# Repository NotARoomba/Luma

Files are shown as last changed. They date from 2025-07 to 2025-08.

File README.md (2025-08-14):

<h1 align="center">
  <br>
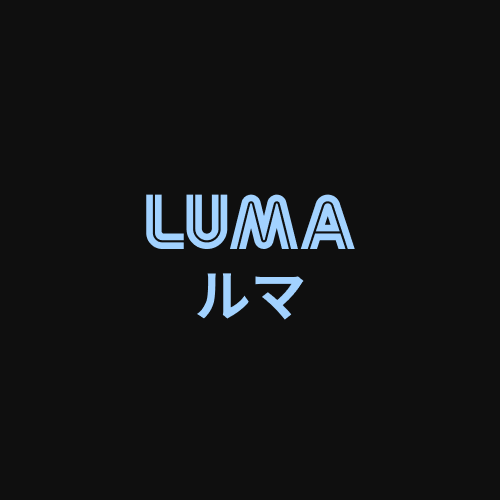
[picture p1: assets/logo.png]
Luma
  
  <br>
  Luma
  <br>
</h1>

<h4 align="center">
A Minecraft inspired lantern with bluetooth!

</h4>

<div align="center">





</div>

<p align="center">
  <a href="#key-features">Key Features</a> •
  <a href="#case-and-cad">Case & CAD</a> •
  <a href="#pcb">PCB</a> •
  <a href="#bom">BOM</a> •
  <a href="#credits">Credits</a> •
  <a href="#license">License</a>
</p>

## Key Features

- Bluetooth/Wifi capabilitis
- Bright configurable LED's
- Easy to assemble case
- App to control/change colors

## Case and CAD

The case includes:

- 3D printed parts: The base, walls, top, and chain
- Glueable inserts and acrylic panes

Designed in Fusion 360.

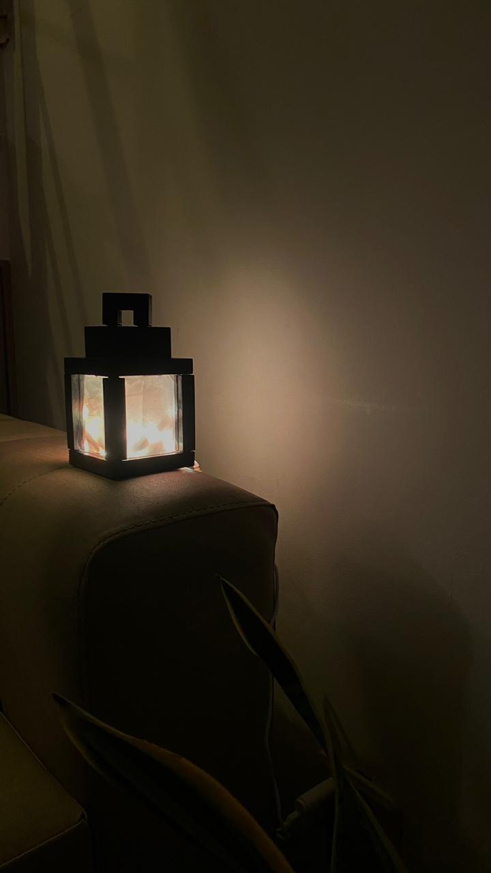
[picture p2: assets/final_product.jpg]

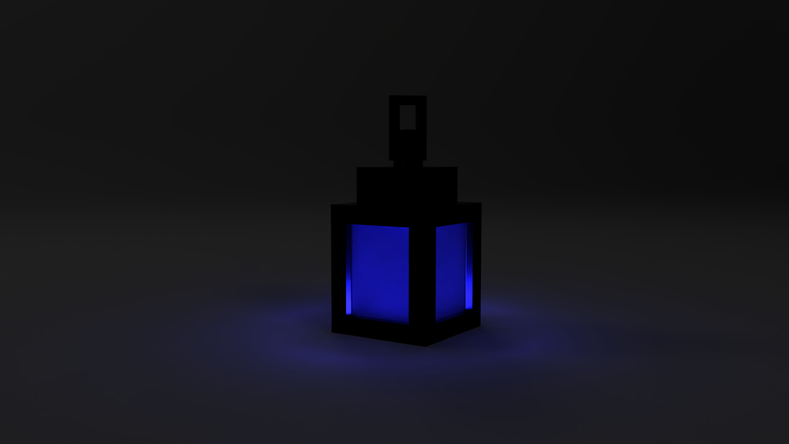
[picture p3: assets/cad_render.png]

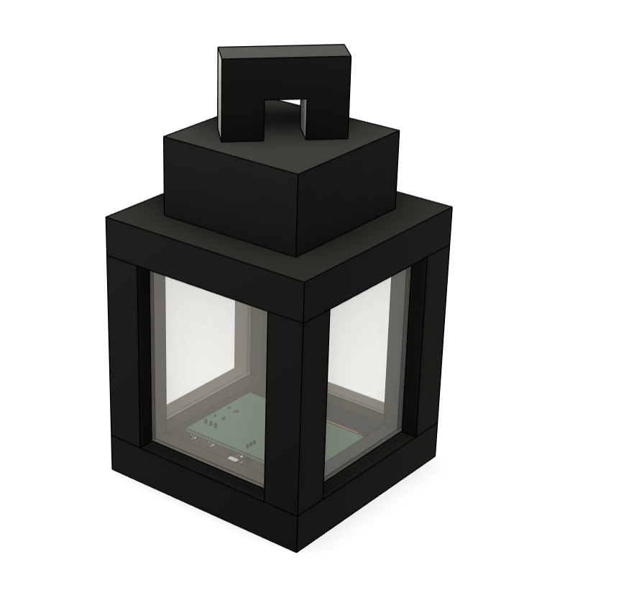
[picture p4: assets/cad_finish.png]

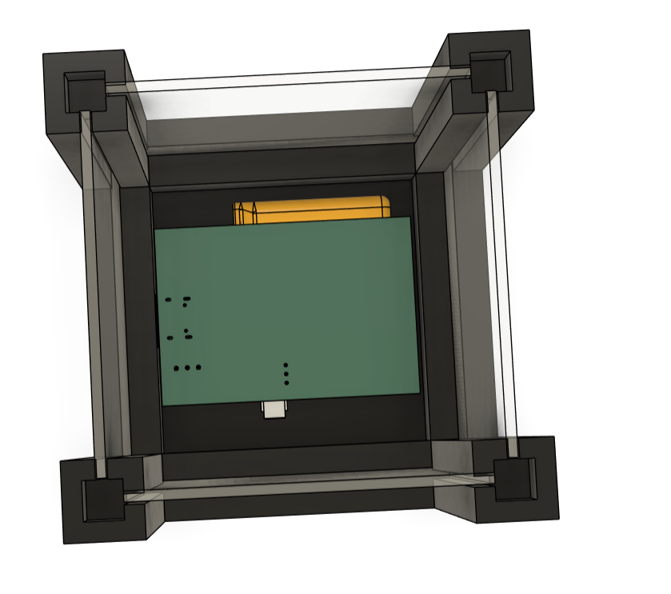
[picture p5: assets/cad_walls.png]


## PCB

Designed in KiCad. Notable points:

- ESP32-WROOM-32E for bluetooth support
- LiPo battery charging circuit
- USB-C
- LED Header to add custom LED's

### Main Board

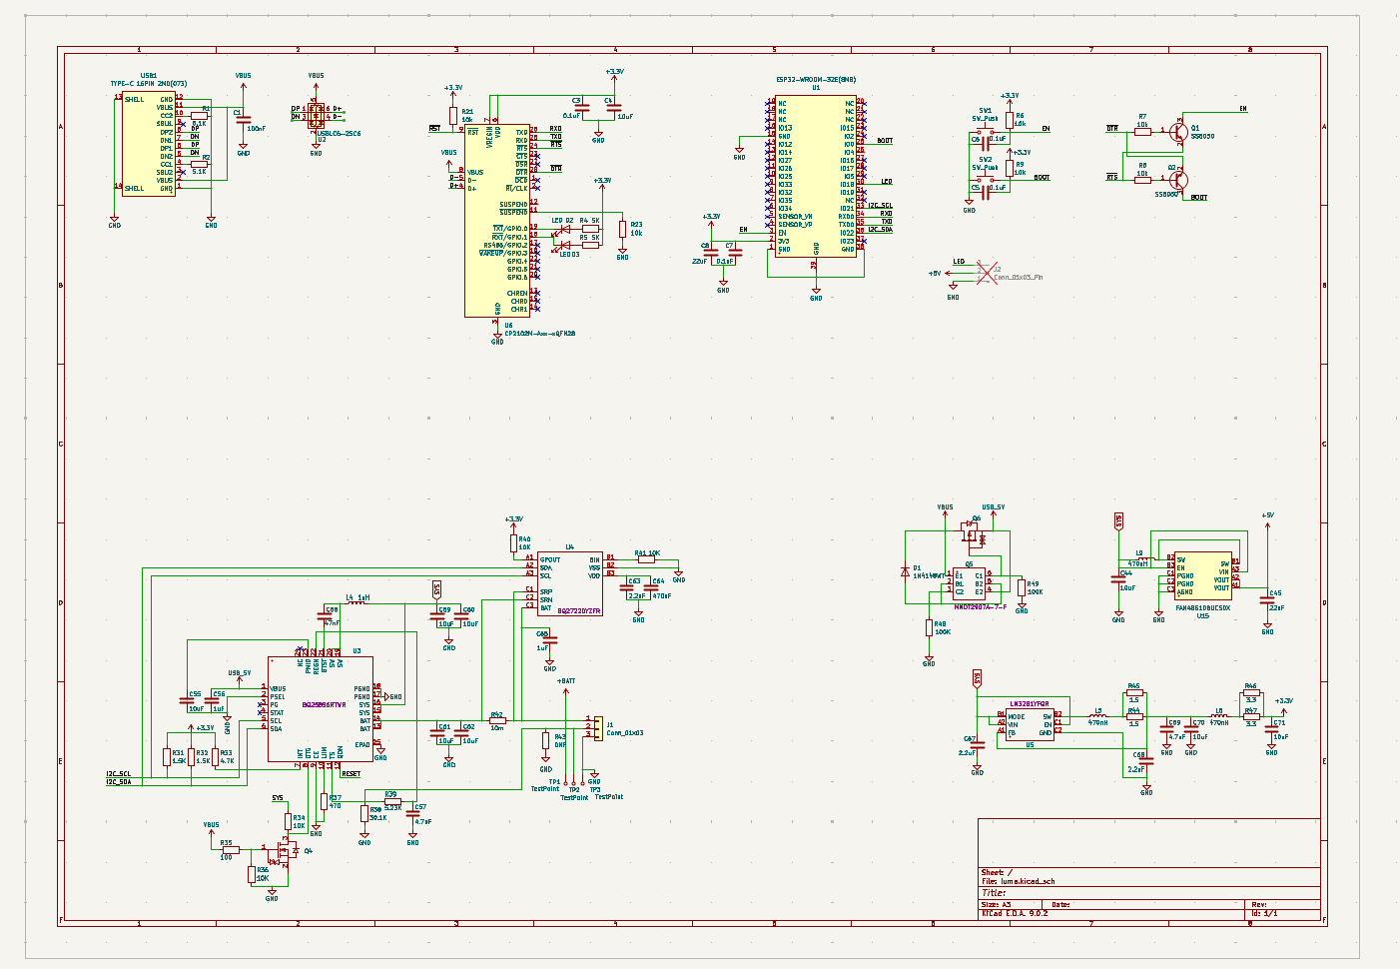
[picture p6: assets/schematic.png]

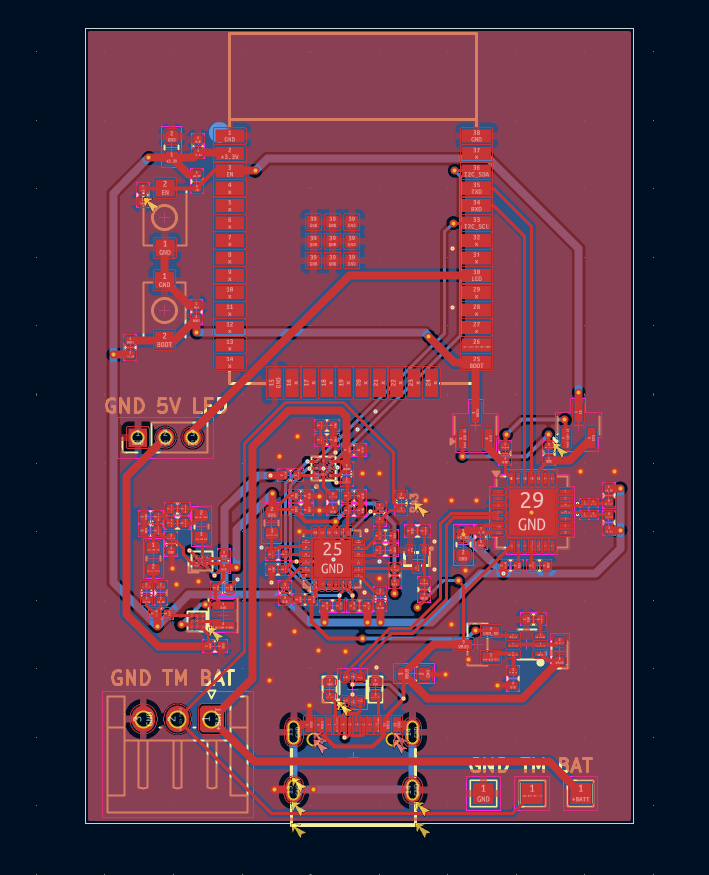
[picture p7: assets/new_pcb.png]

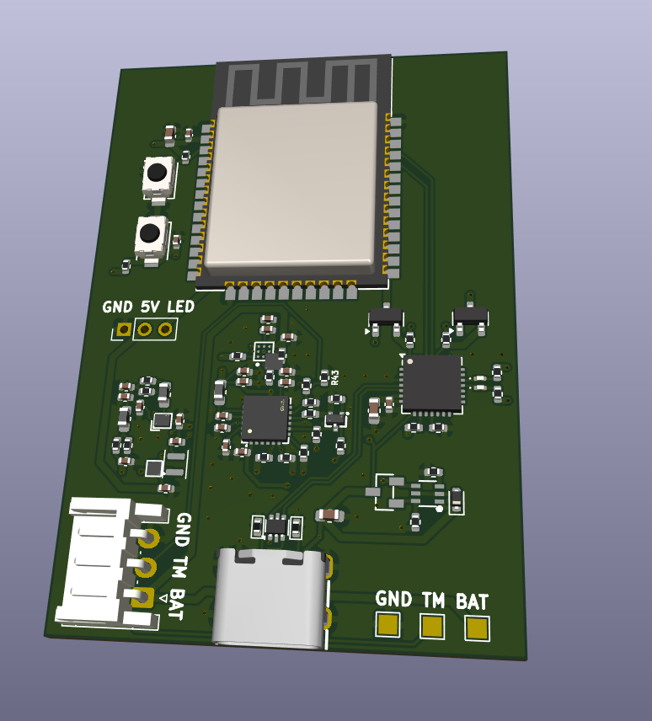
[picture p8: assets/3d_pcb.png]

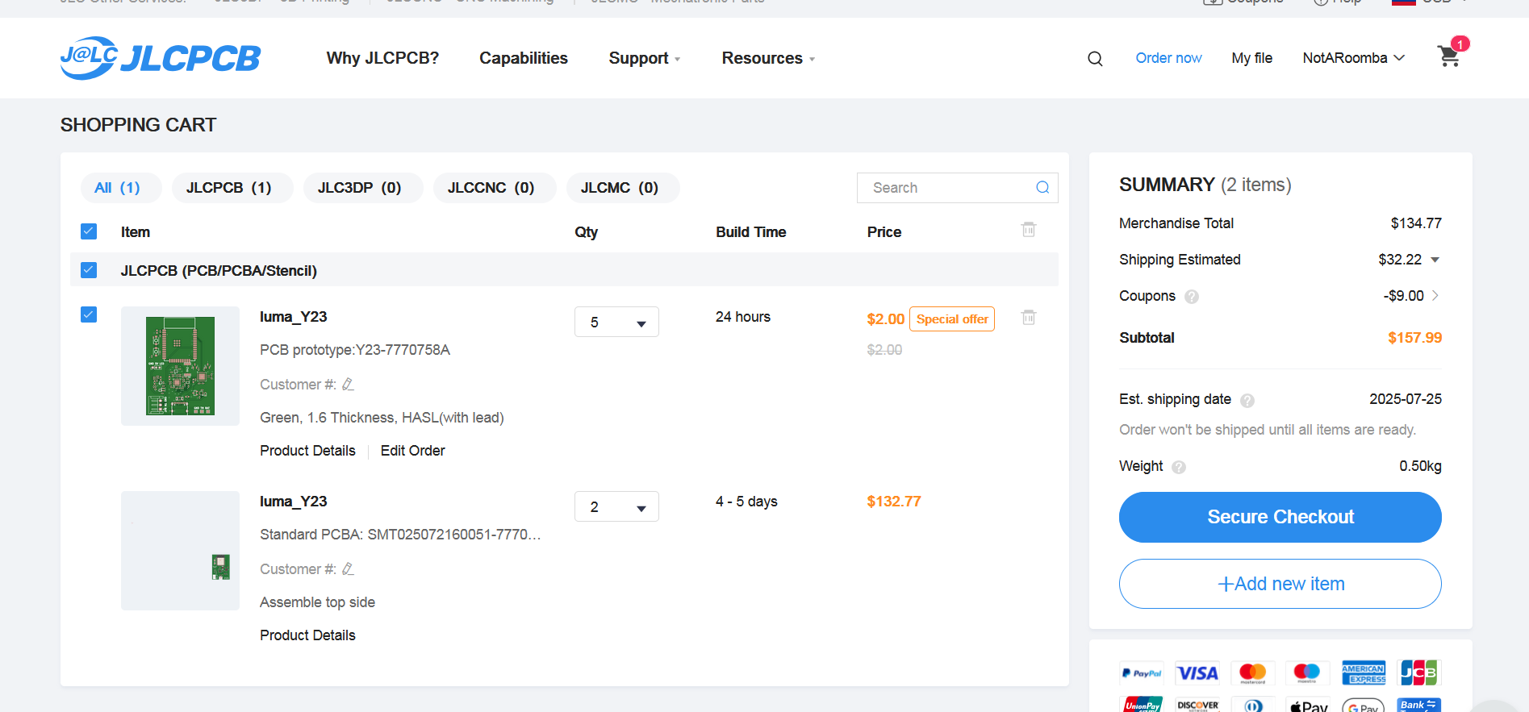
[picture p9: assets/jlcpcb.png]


## BOM

| Item | Price (USD) | Source |
| --- | --- | --- |
| PCB | 134.77 | JLCPCB |
| 3D Printed Parts | 0.00 | (already have a 3D printer) |
| Acrylic Panes | 0.00 | (already have) |
| LED Strip | 0.00 | (already have) |
| LiPo 1200mAh | 12.00 | [Online Marketplace (Aliexpress takes 1 month)](https://articulo.mercadolibre.com.co/MCO-897219547-bateria-37v-1200mah-litio-lipo-35-x-6cm-ancho-05cm-_JM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) |
| **Total** | 146.77 | |

## Credits

This project uses:

- [KiCad](https://www.kicad.org/)
- [VSCode](https://code.visualstudio.com/)
- [Fusion 360](https://www.autodesk.com/products/fusion-360/overview)

## You may also like...

- [Niveles De Niveles](https://github.com/NotARoomba/NivelesDeNiveles) – Real-time flood alert app
- [Linea](https://github.com/NotARoomba/Linea) – An EMR tablet
- [Tamaki](https://github.com/NotARoomba/Tamaki) – A cute HackPad

## License

MIT

---

> [notaroomba.dev](https://notaroomba.dev) &nbsp;&middot;&nbsp;
> GitHub [@NotARoomba](https://github.com/NotARoomba)

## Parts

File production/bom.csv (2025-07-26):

Designator | Footprint | Quantity | Value | LCSC Part #
C1 | 0603 | 1 | 100nF
C3, C5, C6, C7 | 0402 | 4 | 0.1uF
C4 | 0603 | 1 | 10uF
C44, C55, C59, C60, C61, C62, C70, C71 | 0402 | 8 | 10uF
C45 | 0402 | 1 | 22uF
C56, C65 | 0402 | 2 | 1uF
C57, C69 | 0402 | 2 | 4.7uF
C58 | 0402 | 1 | 47nF
C63, C67, C68 | 0402 | 3 | 2.2uF
C64 | 0402 | 1 | 470nF
C8 | 0603 | 1 | 22uF
D1 | D_SOD-523 | 1 | 1N4148WT
D2, D3 | 0201 | 2 | LED
J1 | JST_EH_S3B-EH_1x03_P2.50mm_Horizontal | 1 | Conn_01x03 | C263754
J2 | PinHeader_1x03_P2.00mm_Vertical | 1 | Conn_01x03_Pin
L4 | 0603 | 1 | 1uH
L5, L6 | 0603 | 2 | 470nH
L9 | L_Murata_DFE201610P | 1 | 470nH | C882980
Q1, Q2 | SOT-23 | 2 | SS8050 | SS8050-HF
Q4 | SOT-523-3_L1.6-W0.8-P1.00-LS1.6-BR | 1 | ~ | C155524
Q5 | SOT-363_L2.0-W1.3-P0.65-LS2.1-BL | 1 | ~ | C460232
Q6 | SOT-23-3_L2.9-W1.3-P1.90-LS2.4-BR | 1 | ~ | C177033
R1, R2 | 0402 | 2 | 5.1K
R21, R23, R6, R7, R8, R9 | 0402 | 6 | 10k | CRCW040210K0FKED
R31, R32 | 0402 | 2 | 1.5K
R33 | 0402 | 1 | 4.7K
R34, R36, R40, R41 | 0402 | 4 | 10K
R35 | 0402 | 1 | 100
R37 | 0402 | 1 | 470
R38 | 0402 | 1 | 30.1K
R39 | 0402 | 1 | 5.23K
R4, R5 | 0402 | 2 | 5K | CRCW040210K0FKED
R42 | R2512 | 1 | WW25WR010FTL | C171418
R43 | 0402 | 1 | DNP
R44, R45 | 0402 | 2 | 1.5
R46, R47 | 0402 | 2 | 3.3
R48, R49 | 0402 | 2 | 100K
SW1, SW2 | SW-SMD_L3.9-W3.0-P4.45 | 2 | SW_Push | C720477
TP1, TP2, TP3 | TestPoint_Pad_1.5x1.5mm | 3 | TestPoint
U1 | WIFI-SMD_ESP32-WROOM-32E | 1 | ESP32-WROOM-32E(8MB) | C701342
U15 | WLCSP-9_L1.2-W1.2-R3-C3-P0.40-BL | 1 | FAN48610BUC50X | C890711
U2 | SOT-666 | 1 | USBLC6-2SC6 | USBLC6-2SC6
U3 | QFN-24_L4.0-W4.0-P0.50-TL-EP2.7 | 1 | ~ | C181475
U4 | DSBGA-9_L1.7-W1.6-R3-C3-P0.50-BL | 1 | ~ | C528617
U5 | DSBGA-6_L1.4-W1.1-R3-C2-P0.40-BL | 1 | ~ | C2070970
U6 | QFN-28-1EP_5x5mm_P0.5mm_EP3.35x3.35mm | 1 | CP2102N-Axx-xQFN28 | C964632
USB1 | USB-C-SMD_TYPE-C-6PIN-2MD-073 | 1 | TYPE-C 16PIN 2MD(073) | C2765186

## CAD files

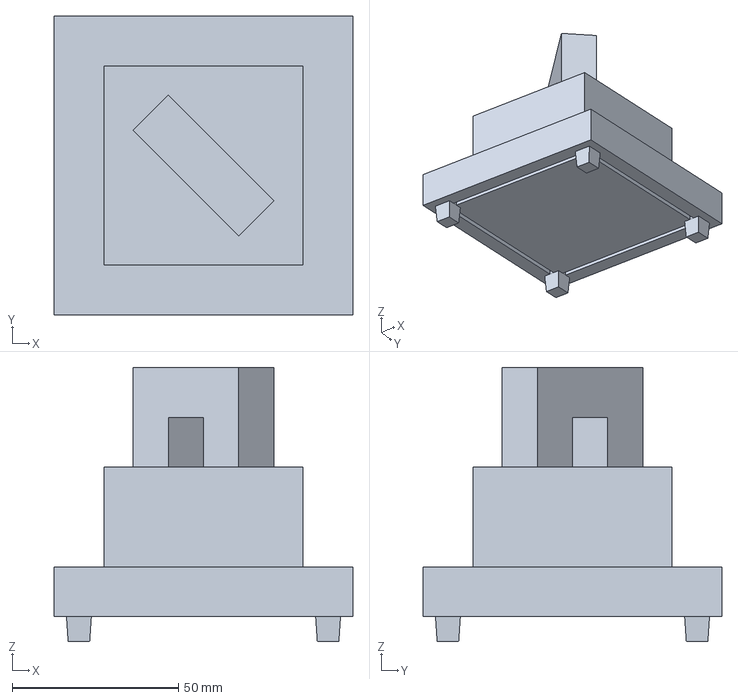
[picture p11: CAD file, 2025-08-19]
production/Top_Complete.step
90.0 x 90.0 x 82.5 mm

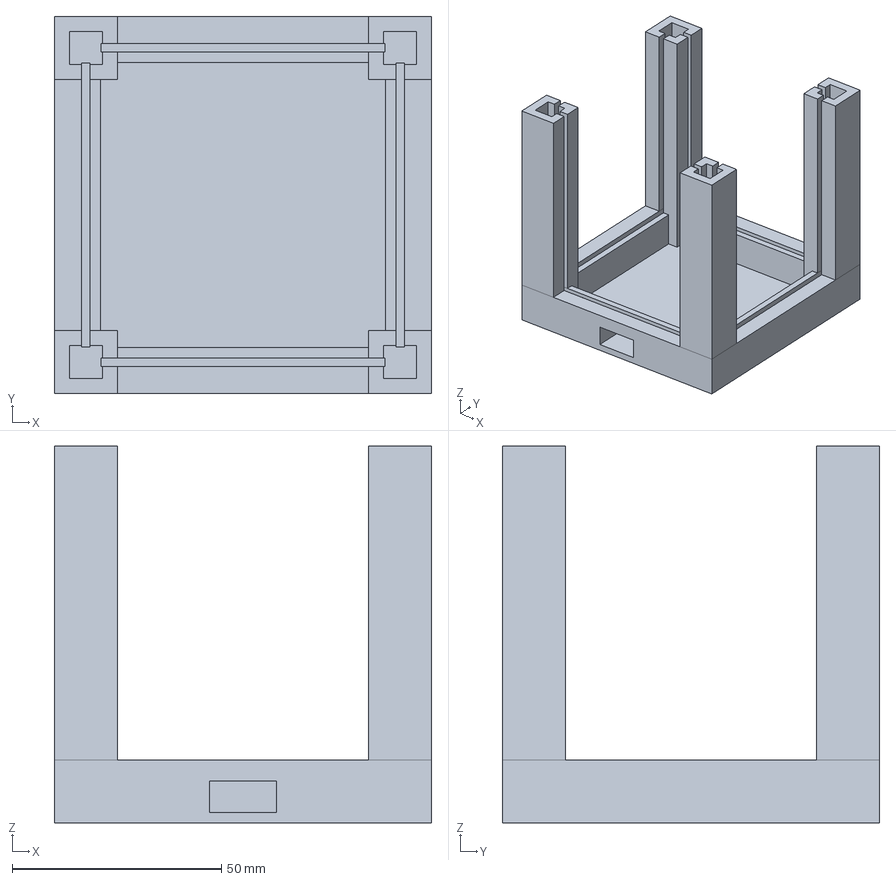
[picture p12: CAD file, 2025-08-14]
production/Base_Complete.step
90.0 x 90.0 x 90.0 mm

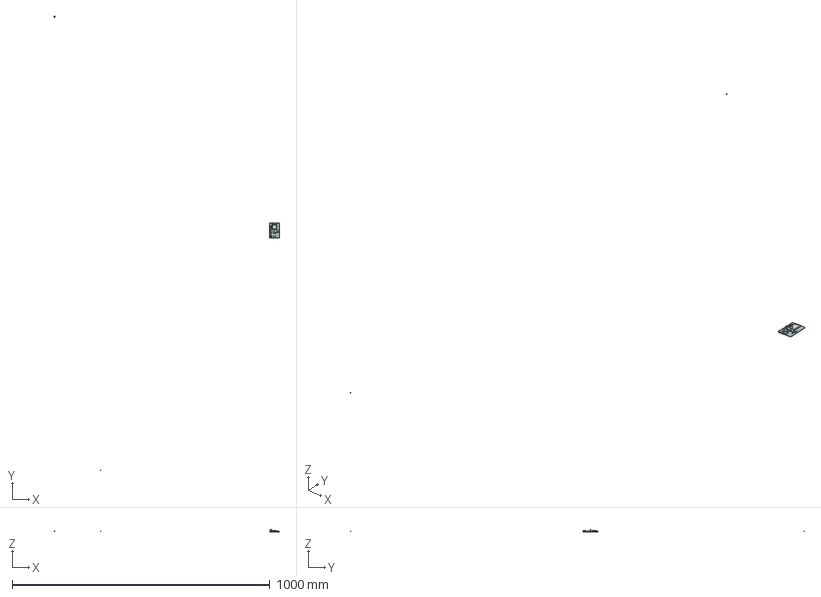
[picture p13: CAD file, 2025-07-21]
hardware/pcb/luma.step
874.2 x 1760.2 x 9.20 mm
QFN-28-1EP_5x5mm_P0.5mm_EP3.35x3.35mm
C_0603_1608Metric x 3
R_0402_1005Metric x 29
JST_EH_S3B-EH_1x03_P2.50mm_Horizontal
C_0402_1005Metric x 22
SW-SMD_L3.9-W2.9-H2.0-LS4.8 x 2
L_0603_1608Metric x 3
SOT-363-6P_L2.0-W1.3-H1.1-LS2.0-P0.65
SOT-23 x 2
SOT-23-3P_L2.9-W1.3-H1.0-LS2.4-P0.95
WIFI-SMD_L25.5-W18.0-H3.1-ESP32-WROOM-32E
SOT-523-3P_L1.6-W0.8-H0.9-LS1.6-P0.50
DSBGA-6_L1.4-W1.1-R3-C2-P0.40-BL
LED_0201_0603Metric x 2
QFN-24_L4.0-W4.0-P0.50-TL-EP2.7
DSBGA-9_L1.7-W1.6-H0.6-R3-C3-P0.50-BL
SOT-666
USB-C-SMD_TYPE-C-6PIN-2MD-073
PinHeader_1x03_P2.00mm_Vertical
D_SOD-523
WLCSP-9_L1.2-W1.2-H0.6-R3-C3-P0.40-BL
luma_PCB

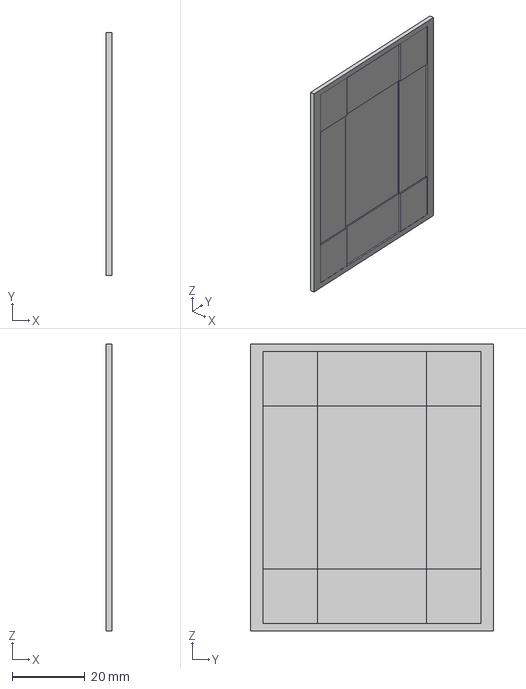
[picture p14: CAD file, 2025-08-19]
production/Window.step
1.60 x 67.0 x 79.0 mm

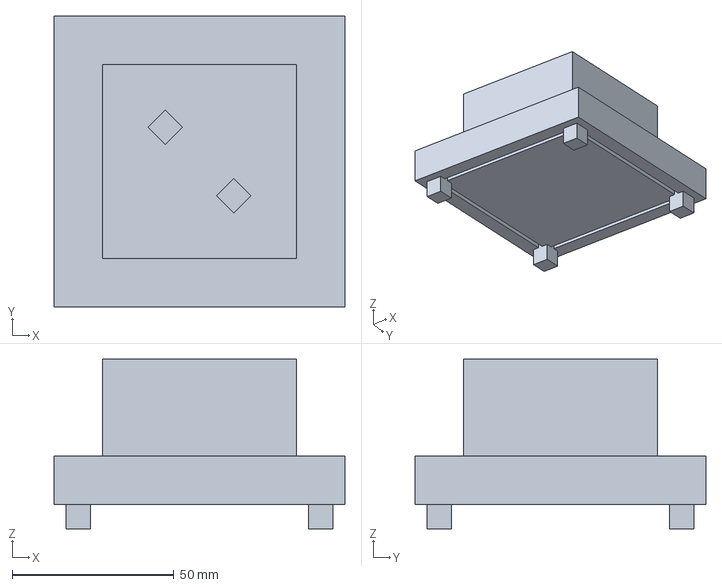
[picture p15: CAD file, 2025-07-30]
production/Top.step
90.0 x 90.0 x 52.5 mm

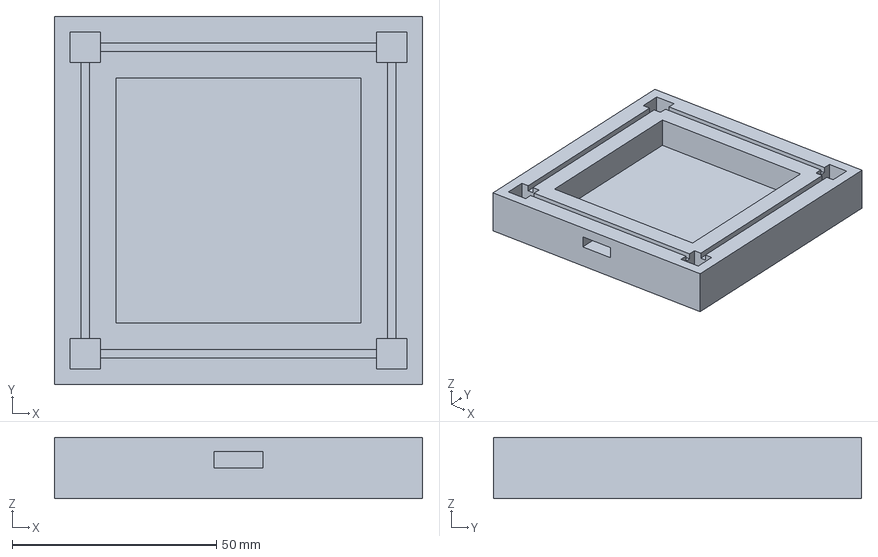
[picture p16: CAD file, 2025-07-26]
production/Bottom.step
90.0 x 90.0 x 15.0 mm

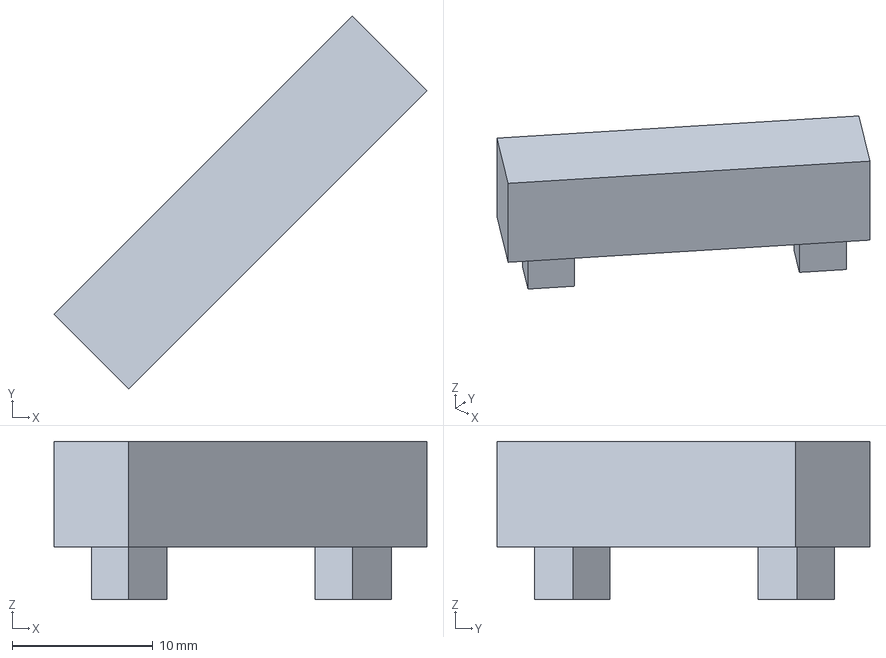
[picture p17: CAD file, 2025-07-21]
production/Chain_Top.step
26.5 x 26.5 x 11.2 mm

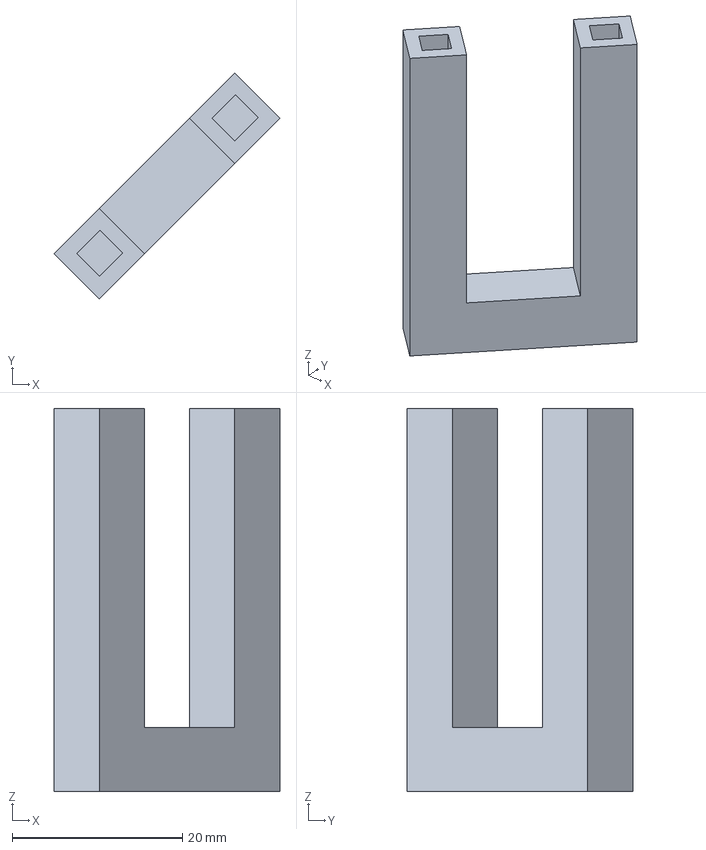
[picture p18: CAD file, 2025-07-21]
production/Chain_Bottom.step
26.5 x 26.5 x 45.0 mm

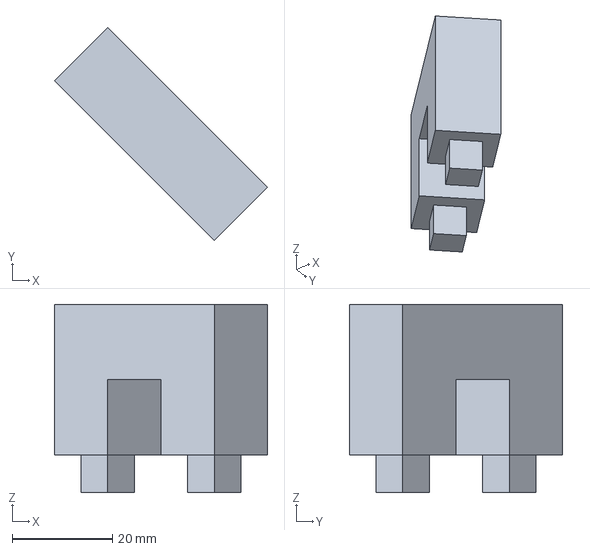
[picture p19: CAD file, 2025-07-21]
production/Handle.step
42.4 x 42.4 x 37.5 mm

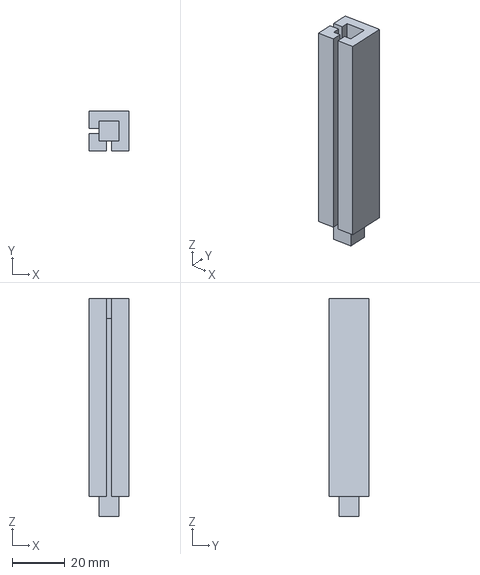
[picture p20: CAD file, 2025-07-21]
production/Leg.step
15.0 x 15.0 x 82.5 mm

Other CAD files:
hardware/cad/Luma v33.f3z
hardware/cad/Luma v40.f3z
production/Window.f3z

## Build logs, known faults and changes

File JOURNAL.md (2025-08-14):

---
title: "Luma"
author: "Nathan Alspaugh (NotARoomba)"
description: "A minecraft inspired lantern controllable by a custom app."
created_at: "2025-07-16"
time_spent: ~21 Hours
---

# July 16: Start and Schematic Design

I was scrolling TikTok out of boredom when I found a minecraft lantern that someone was selling and that could be controlled by an IR remote and in that moment I thought of a way to improve it so that's when Luma was started. I wanted to make a minecraft lantern that can be controlld by an app/bluetooth and that you can give to your friends to communicate through lights.

To do this I would need a chip that has bluetooth/wifi (I have designd my own before and would like to save myself the time lol) so I ended up using an ESP32-WROOM-32E(8MB) along with 9 LED's in a 3x3 matrix. I planned on having it be charged through USB-C and connect to a LiPo battery. I would make the case 3D-printeable and inclue acrylic panels with parchment paper to create a sort of "opacity". After having a clear idea of what I wanted to make, I started wiring up the components.

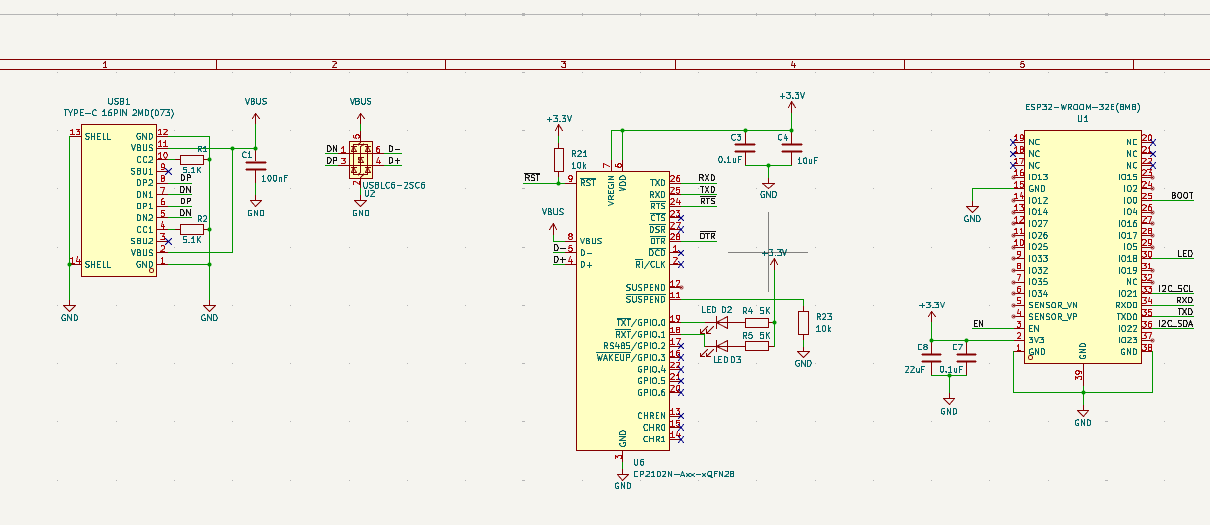
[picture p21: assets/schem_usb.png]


I started off with the ESP32 and the USB-C circuit bassed off of the application note before going to sleep.

**Time Spent:** 4 Hours

# July 17: Finish Schematic and PCB

After making part of the schematic I started work on the battery charging circuits, reusing a design that I implmented in my other project (Linea). Then I added the LED's and connected them to the ESP32.

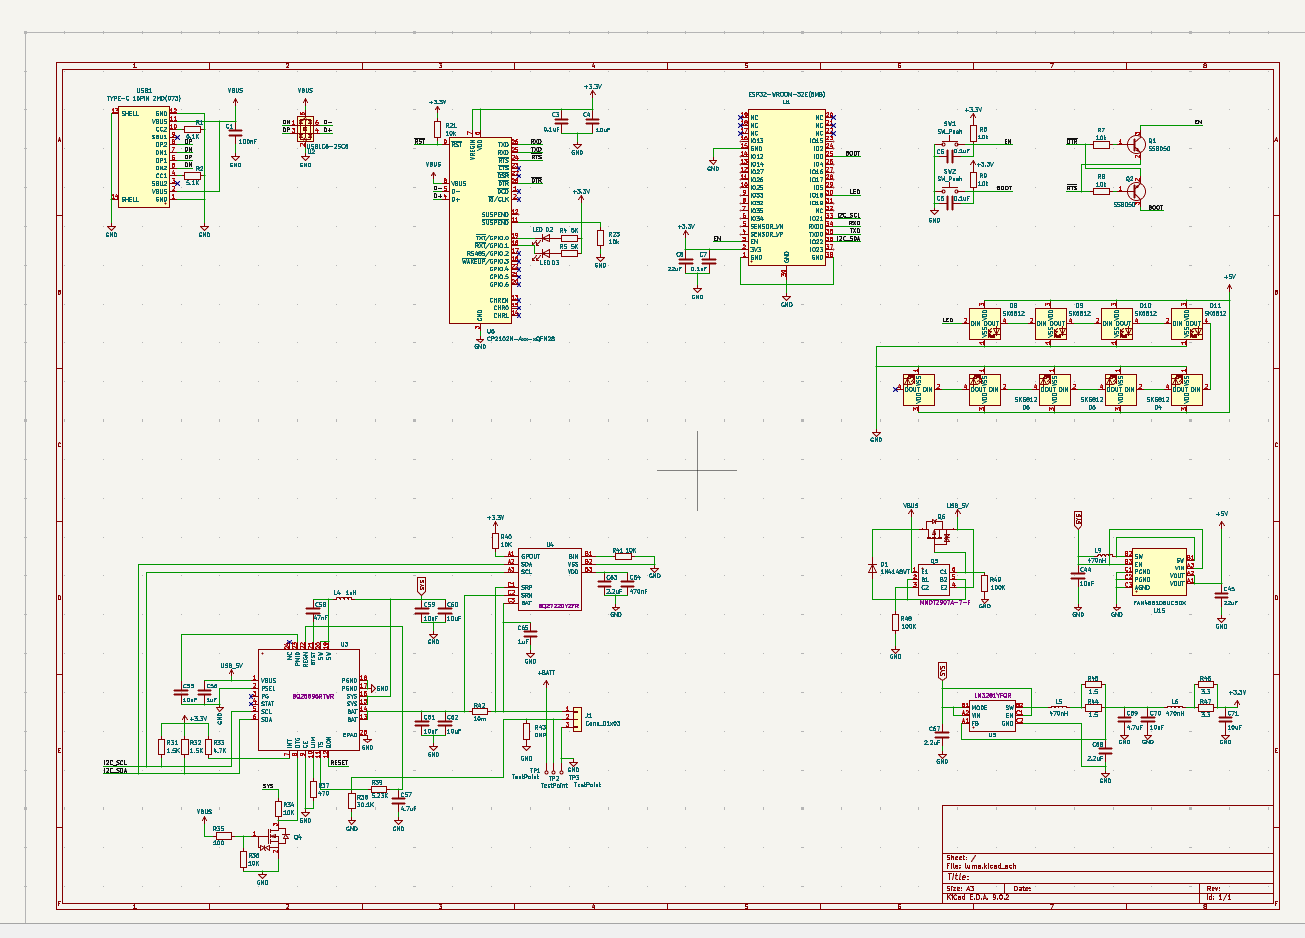
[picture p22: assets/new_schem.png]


After that I started wiring and grouping the components to organize the wiring and make it easier. I decided to make 2 ground planes for the fun of it and wire all the components on one side and then the LED's on the other. I planned on the board being on the bottom or top of the case so the LED's could illuminate the area well.

After a while I ended up with this, but then didn't like how the board was not modular or that I couldn't change the number of LED's (just in case) so I decided to remake the board out of concerns that the 9 LED's wouldn't be bright enough.

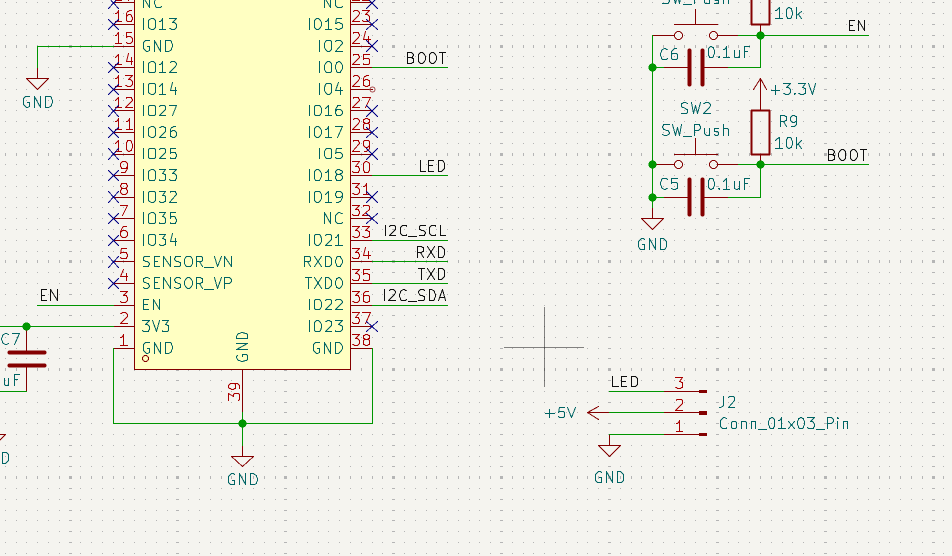
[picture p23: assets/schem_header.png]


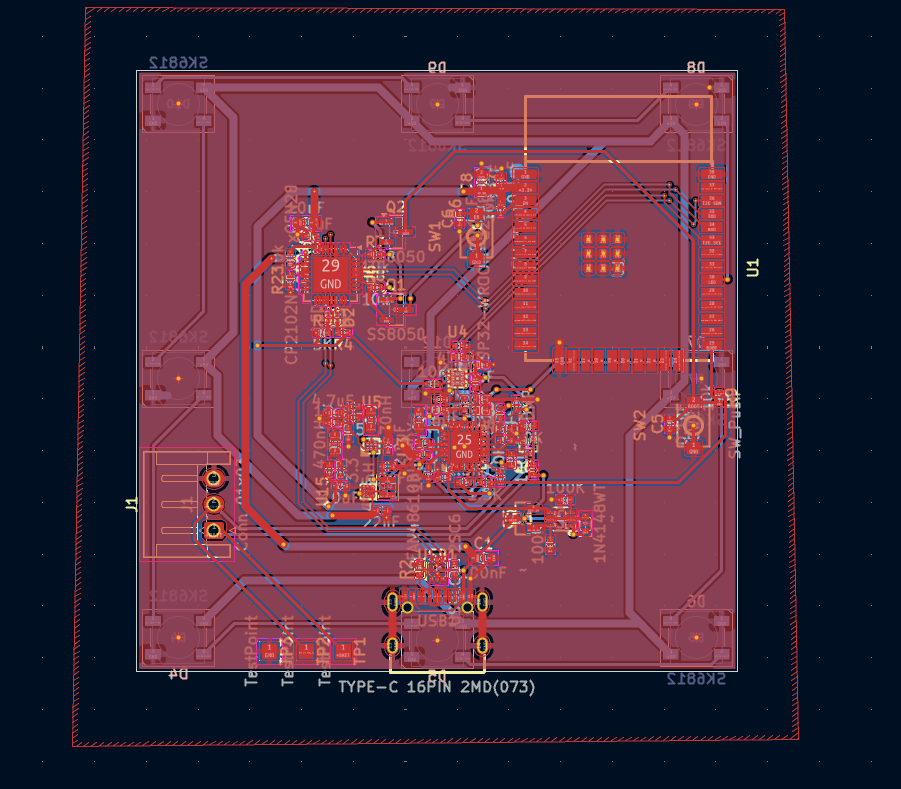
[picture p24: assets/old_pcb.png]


**Time Spent:** 7 Hours

# July 18: Start CAD

I took a break from the schematics and decided to work on the case.
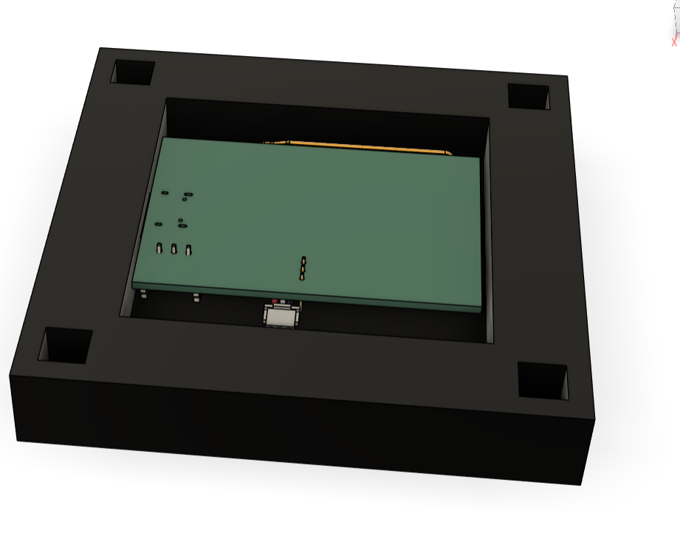
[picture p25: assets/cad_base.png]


I wanted the case to be modular so I created some insets in the base to add the walls.



I then created the walls of the lantern with more insets for the acrylic panels of the case. I decided to use acrylic panels of 2 mm so that the light from inside could get through.



After creating the walls, I added the top (with mroe insets) and then started working on the chains. I also wanted them to be modular and easy to asssemble so I added more inserts to be able to glue them later.

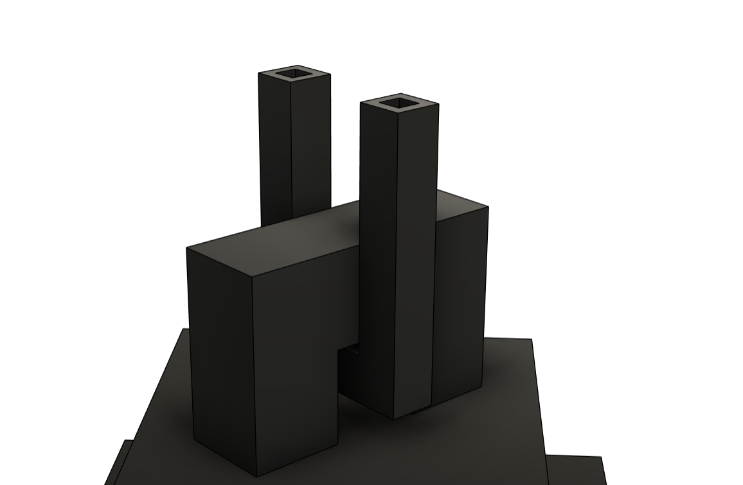
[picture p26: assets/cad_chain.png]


**Time Spent:** 5 Hours

# July 19-20: Finish New PCB and Code

After starting again, I removed all of the LED's and added a header to be able to solder a strip of LED's to allow for a more modular approach.



I also created the code using C++ (arduino). I added a test code to get the lights working as I plan to add the app functionality when I build the lamp.

**Time Spent:** 5 Hours

# August 6

The parts finally came in and I went to work on constructing the lamp before the deadline. Just a tiny problem: I forgot to add tolerances. So I had to hack away at the grooves and the feet of the base and handle as they didn't fit snugly in the holes. I used a Dremel with that circular attachment and kinda melted the plastic, but then I spray painted it black and added all of the components. I'll admit I also had to hack away at the USB-C connector as it was my first time designing something like that and I didn't know how big to make it, but apparently it was too small. I didn't take many photos as my hands were filled with dust and stuff. I did take photos of me buying the paint and acrylic, so here they are along with the final product.

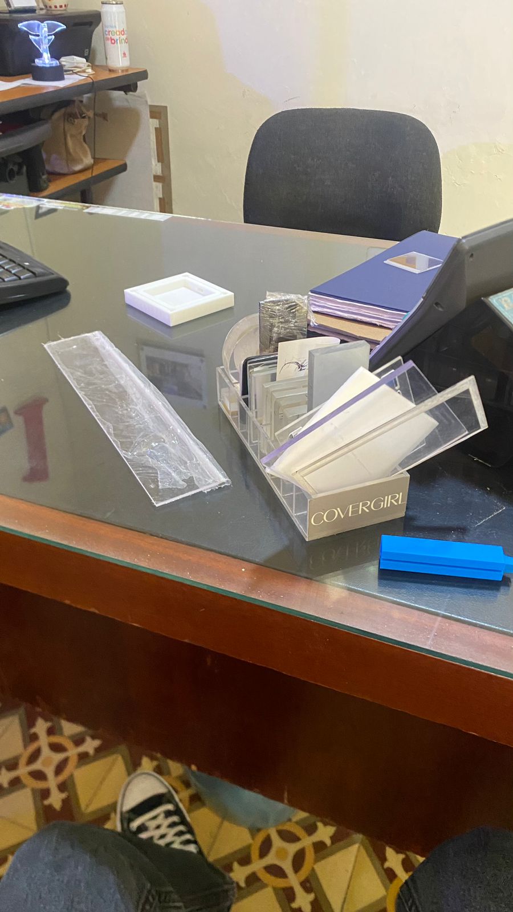
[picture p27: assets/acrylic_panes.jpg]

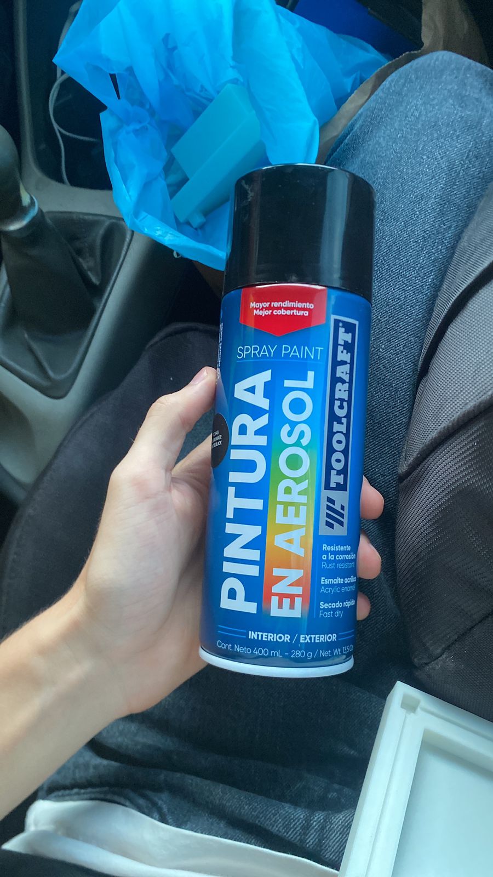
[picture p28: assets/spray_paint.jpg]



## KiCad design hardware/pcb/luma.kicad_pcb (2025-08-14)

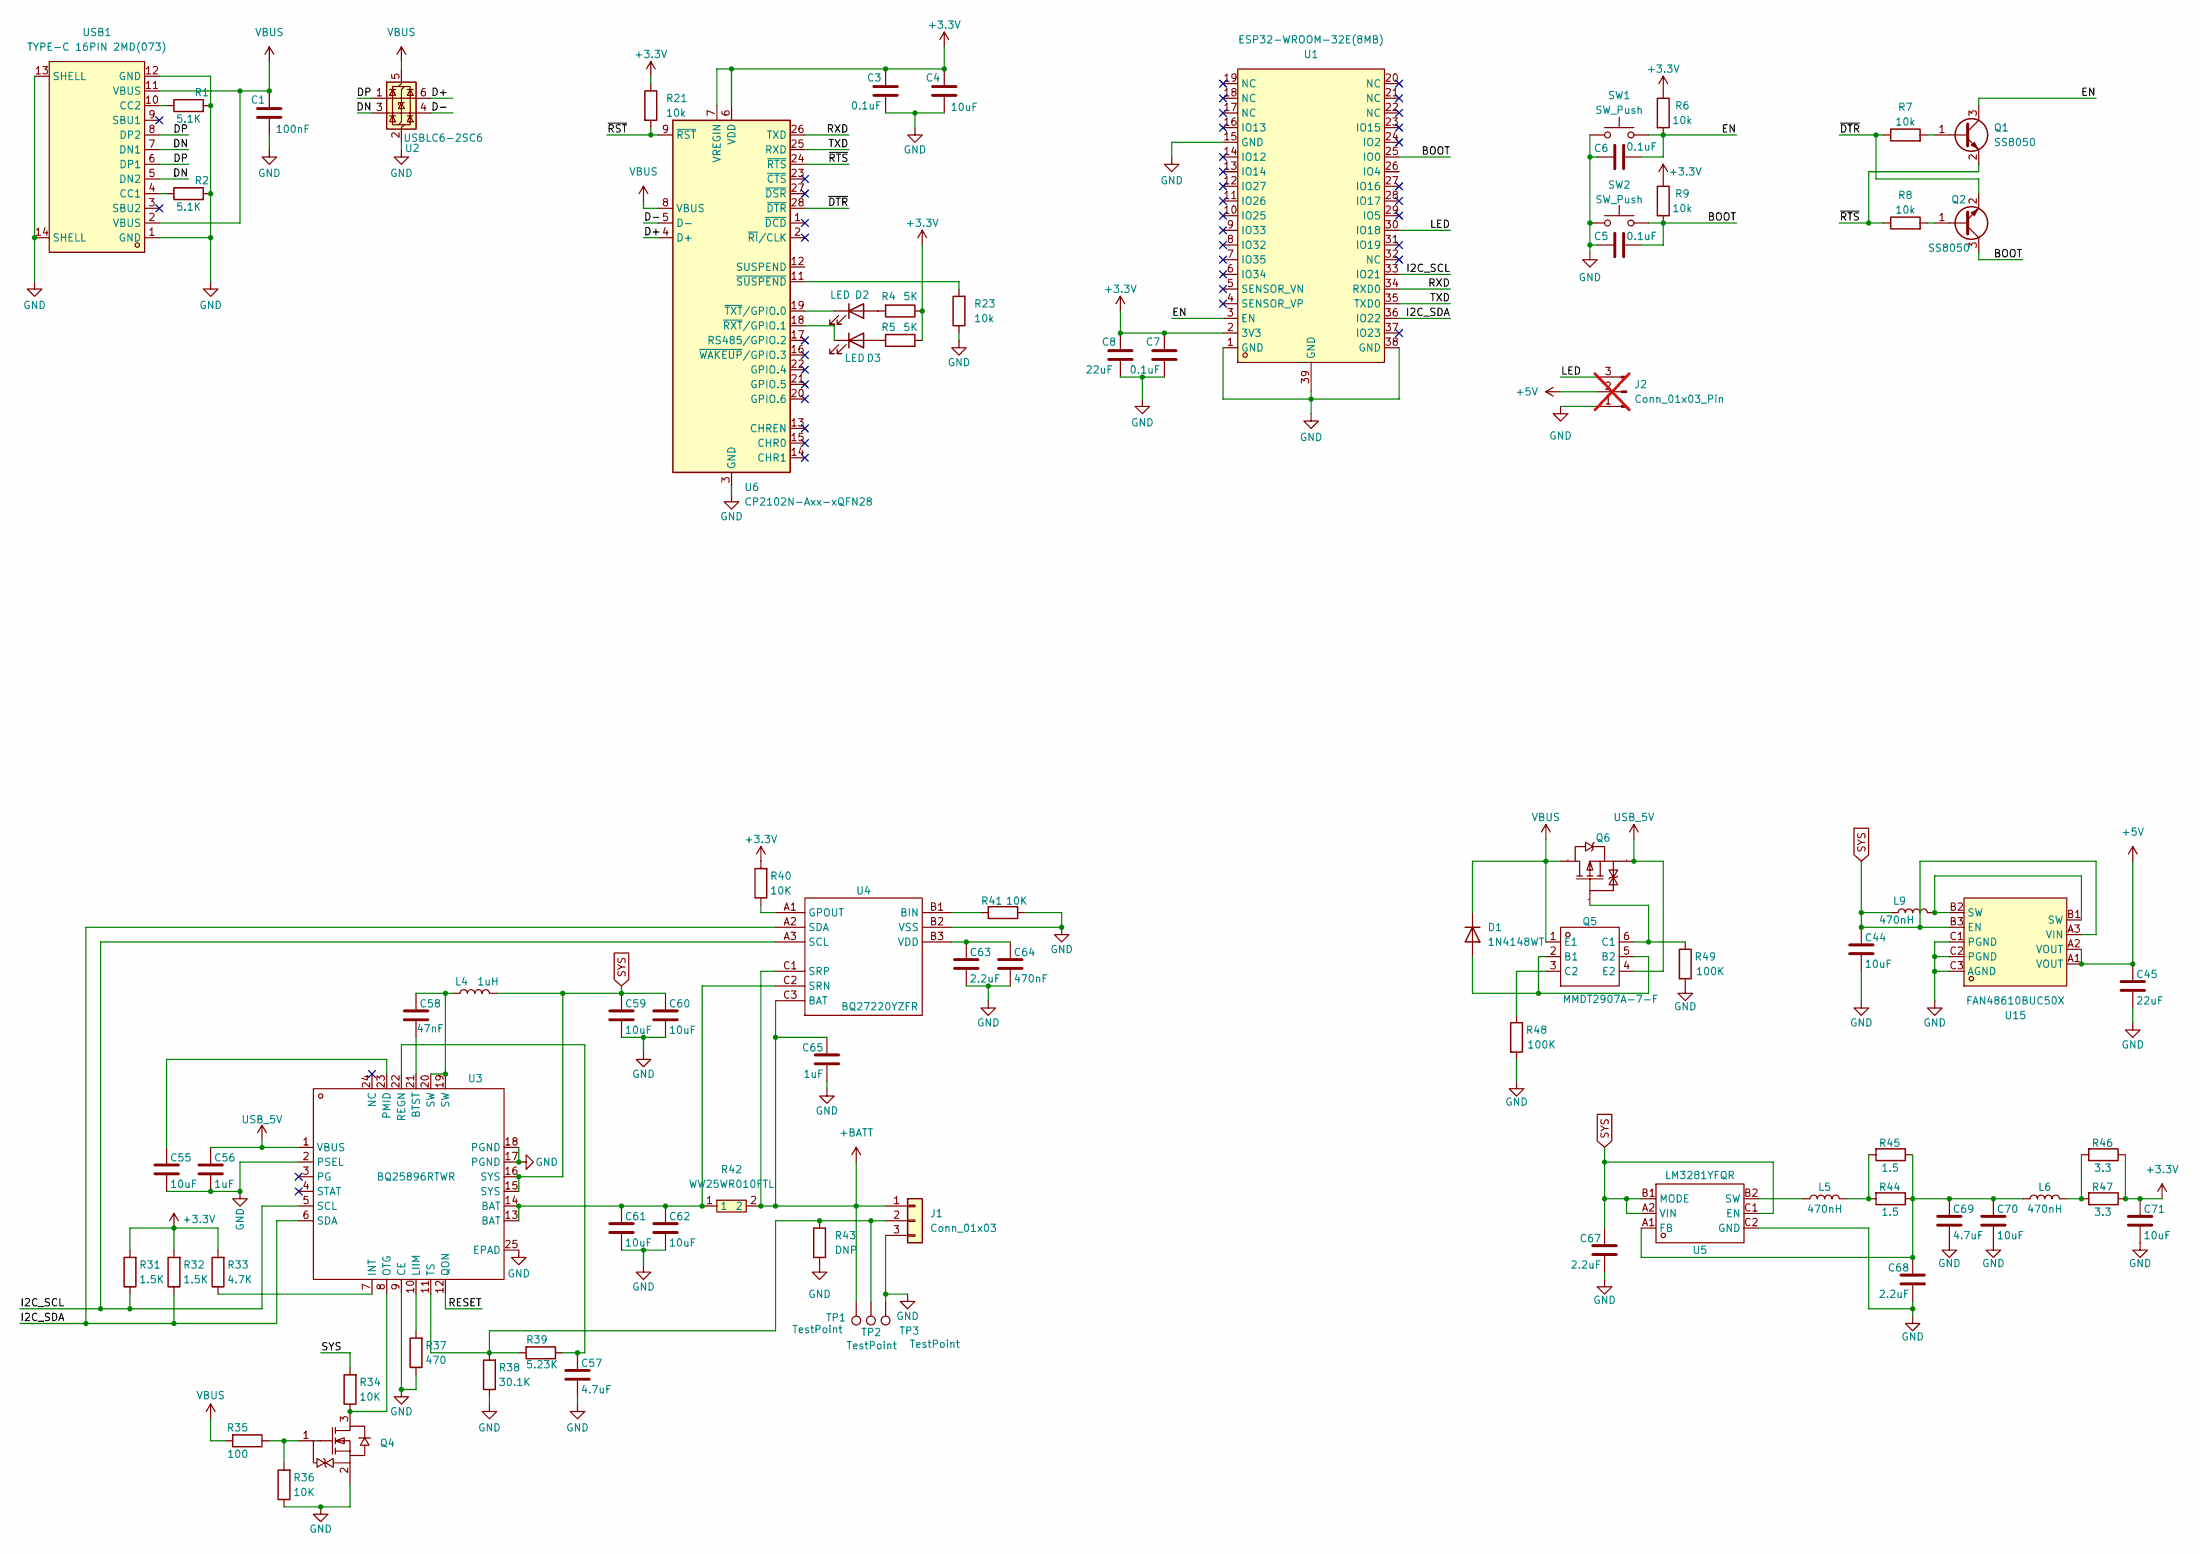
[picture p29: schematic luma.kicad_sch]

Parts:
C1: 100nF; C_0603_1608Metric
C3, C5, C6, C7: 0.1uF; C_0402_1005Metric
C4: 10uF; C_0603_1608Metric
C8: 22uF; C_0603_1608Metric
C44, C55, C59, C60, C61, C62, C70, C71: 10uF; C_0402_1005Metric
C45: 22uF; C_0402_1005Metric
C56, C65: 1uF; C_0402_1005Metric
C57, C69: 4.7uF; C_0402_1005Metric
C58: 47nF; C_0402_1005Metric
C63, C67, C68: 2.2uF; C_0402_1005Metric
C64: 470nF; C_0402_1005Metric
D1: 1N4148WT; D_SOD-523
D2, D3: LED; LED_0201_0603Metric
J1: Conn_01x03; JST_EH_S3B-EH_1x03_P2.50mm_Horizontal; LCSC C263754
J2: Conn_01x03_Pin; PinHeader_1x03_P2.00mm_Vertical; not fitted
L4: 1uH; L_0603_1608Metric
L5, L6: 470nH; L_0603_1608Metric
L9: 470nH; L_Murata_DFE201610P; LCSC C882980
Q1, Q2: SS8050; SOT-23; MPN SS8050-HF
Q4: SOT-523-3_L1.6-W0.8-P1.00-LS1.6-BR; Manufacturer Part DMN313DLT-7; LCSC C155524
Q5: SOT-363_L2.0-W1.3-P0.65-LS2.1-BL; Manufacturer Part MMDT2907A-7-F; LCSC C460232
Q6: SOT-23-3_L2.9-W1.3-P1.90-LS2.4-BR; Manufacturer Part DMP1045U-7; LCSC Part Name 1个P沟道 耐压:12V 电流:4A
R1, R2: 5.1K; R_0402_1005Metric
R4, R5: 5K; R_0402_1005Metric; MPN CRCW040210K0FKED
R6, R7, R8, R9, R21, R23: 10k; R_0402_1005Metric; MPN CRCW040210K0FKED
R31, R32: 1.5K; R_0402_1005Metric
R33: 4.7K; R_0402_1005Metric
R34, R36, R40, R41: 10K; R_0402_1005Metric
R35: 100; R_0402_1005Metric
R37: 470; R_0402_1005Metric
R38: 30.1K; R_0402_1005Metric
R39: 5.23K; R_0402_1005Metric
R42: WW25WR010FTL; R2512; LCSC Part C171418
R43: DNP; R_0402_1005Metric
R44, R45: 1.5; R_0402_1005Metric
R46, R47: 3.3; R_0402_1005Metric
R48, R49: 100K; R_0402_1005Metric
SW1, SW2: SW_Push; SW-SMD_L3.9-W3.0-P4.45; LCSC C720477
TP1, TP2, TP3: TestPoint; TestPoint_Pad_1.5x1.5mm
U1: ESP32-WROOM-32E(8MB); WIFI-SMD_ESP32-WROOM-32E; LCSC Part C701342
U2: USBLC6-2SC6; SOT-666; MPN USBLC6-2SC6
U3: QFN-24_L4.0-W4.0-P0.50-TL-EP2.7; Manufacturer Part BQ25896RTWR; LCSC C181475
U4: DSBGA-9_L1.7-W1.6-R3-C3-P0.50-BL; Manufacturer Part BQ27220YZFR; LCSC C528617
U5: DSBGA-6_L1.4-W1.1-R3-C2-P0.40-BL; Manufacturer Part LM3281YFQR; LCSC C2070970
U6: CP2102N-Axx-xQFN28; QFN-28-1EP_5x5mm_P0.5mm_EP3.35x3.35mm; LCSC C964632
U15: FAN48610BUC50X; WLCSP-9_L1.2-W1.2-R3-C3-P0.40-BL; LCSC Part C890711
USB1: TYPE-C 16PIN 2MD(073); USB-C-SMD_TYPE-C-6PIN-2MD-073; LCSC Part C2765186

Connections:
+3.3V: C3.1, C4.1, C7.1, C8.1, C71.1, R4.1, R5.1, R6.1, R9.1, R21.1, R31.2, R32.2, R33.2, R40.2, R46.1, R47.1, U1.2 (3V3), U6.6 (VDD), U6.7 (VREGIN)
+5V: C45.1, J2.2, U15.A1 (VOUT), U15.A2 (VOUT)
+BATT: C65.1, J1.1, R42.2, TP1.1, U4.C1 (SRP), U4.C3 (BAT)
/BOOT: C5.2, Q2.3 (C), R9.2, SW2.2, U1.25 (IO0)
/D+: U2.6 (I/O1), U6.4 (D+)
/D-: U2.4 (I/O2), U6.5 (D-)
/DN: U2.3 (I/O2), USB1.5 (DN2), USB1.7 (DN1)
/DP: U2.1 (I/O1), USB1.6 (DP1), USB1.8 (DP2)
/EN: C6.2, Q1.3 (C), R6.2, SW1.2, U1.3 (EN)
/I2C_SCL: R31.1, U1.33 (IO21), U3.5 (SCL), U4.A3 (SCL)
/I2C_SDA: R32.1, U1.36 (IO22), U3.6 (SDA), U4.A2 (SDA)
/LED: J2.3, U1.30 (IO18)
/RESET: U3.12 (QON)
/RXD: U1.34 (RXD0), U6.26 (TXD)
/TXD: U1.35 (TXD0), U6.25 (RXD)
/~DTR: Q2.2 (E), R7.1, U6.28 (~DTR)
/~RST: R21.2, U6.9 (~RST)
/~RTS: Q1.2 (E), R8.1, U6.24 (~RTS)
GND: C1.2, C3.2, C4.2, C5.1, C6.1, C7.2, C8.2, C44.2, C45.2, C55.2, C56.2, C57.2, C59.2, C60.2, C61.2, C62.2, C63.2, C64.2, C65.2, C67.2, C68.2, C69.2, C70.2, C71.2, J1.3, J2.1, Q4.2 (S), R1.2, R2.2, R23.1, R36.1, R37.1, R38.1, R41.1, R43.2, R48.2, R49.2, SW1.1, SW2.1, TP3.1, U1.1 (GND), U1.15 (GND), U1.38 (GND), U1.39 (GND), U2.2 (GND), U3.2 (PSEL), U3.9 (CE), U3.17 (PGND), U3.18 (PGND), U3.25 (EPAD), U4.B2 (VSS), U5.C2 (GND), U6.3 (GND), U6.29 (GND), U15.C1 (PGND), U15.C2 (PGND), U15.C3 (AGND), USB1.1 (GND), USB1.12 (GND), USB1.13 (SHELL), USB1.14 (SHELL)
unnamed: C58.1, L4.1, U3.19 (SW), U3.20 (SW)
unnamed: D1.2 (A), Q5.2 (B1), Q5.5 (B2)
unnamed: D2.2 (A), R4.2
unnamed: D2.1 (K), U6.19 (~TXT/GPIO.0)
unnamed: D3.2 (A), R5.2
unnamed: D3.1 (K), U6.18 (~RXT/GPIO.1)
unnamed: J1.2, R38.2, R39.2, R43.1, TP2.1, U3.11 (TS)
unnamed: L5.2, R44.2, R45.2
unnamed: L6.2, R46.2, R47.2
unnamed: L9.2, U15.B1 (SW), U15.B2 (SW)
unnamed: Q1.1 (B), R7.2
unnamed: Q2.1 (B), R8.2
unnamed: Q4.3 (D), R34.1, U3.8 (OTG)
unnamed: Q4.1 (G), R35.1, R36.2
unnamed: Q5.6 (C1), Q6.1 (G), R49.1
unnamed: Q5.3 (C2), R48.1
unnamed: C58.2, U3.21 (BTST)
unnamed: R33.1, U3.7 (INT)
unnamed: R37.2, U3.10 (LIIM)
unnamed: C55.1, U3.23 (PMID)
unnamed: C57.1, R39.1, U3.22 (REGN)
unnamed: R41.2, U4.B1 (BIN)
unnamed: R40.1, U4.A1 (GPOUT)
unnamed: C61.1, C62.1, R42.1, U3.13 (BAT), U3.14 (BAT), U4.C2 (SRN)
unnamed: C63.1, C64.1, U4.B3 (VDD)
unnamed: C68.1, C69.1, C70.1, L6.1, R44.1, R45.1, U5.A1 (FB)
unnamed: L5.1, U5.B2 (SW)
unnamed: R23.2, U6.11 (~SUSPEND)
unnamed: R2.1, USB1.4 (CC1)
unnamed: R1.1, USB1.10 (CC2)
SYS: C44.1, C59.1, C60.1, C67.1, L4.2, L9.1, R34.2, U3.15 (SYS), U3.16 (SYS), U5.A2 (VIN), U5.B1 (MODE), U5.C1 (EN), U15.A3 (VIN), U15.B3 (EN)
USB_5V: C56.1, Q5.4 (E2), Q6.2 (S), U3.1 (VBUS)
VBUS: C1.1, D1.1 (K), Q5.1 (E1), Q6.3 (D), R35.2, U2.5 (VBUS), U6.8 (VBUS), USB1.2 (VBUS), USB1.11 (VBUS)

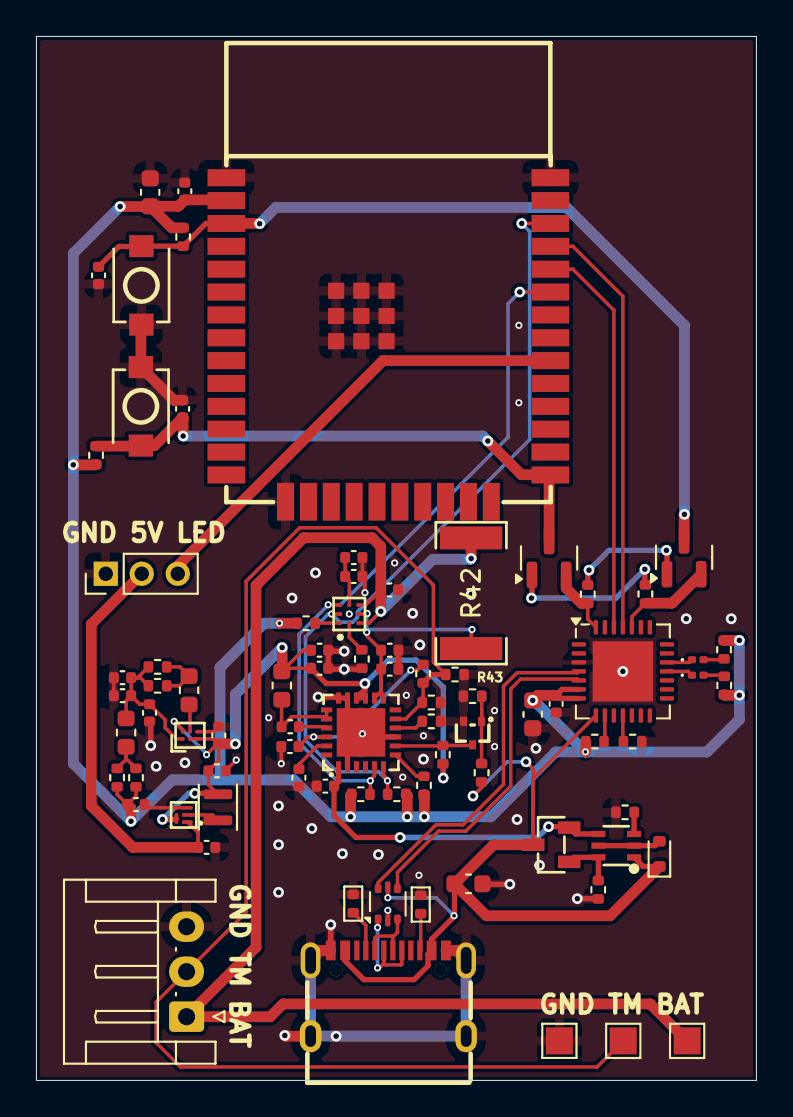
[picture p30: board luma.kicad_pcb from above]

Board: 2 copper layers, 40.0 x 58.0 mm, 81 parts (0 on the bottom side), 51 nets.

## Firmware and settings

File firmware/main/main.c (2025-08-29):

/*
 * SPDX-FileCopyrightText: 2010-2022 Espressif Systems (Shanghai) CO LTD
 *
 * SPDX-License-Identifier: CC0-1.0
 */

#include <stdio.h>
#include <inttypes.h>
#include "sdkconfig.h"
#include "freertos/FreeRTOS.h"
#include "freertos/task.h"
#include "esp_chip_info.h"
#include "esp_flash.h"
#include "esp_system.h"
#include "esp_log.h"
#include "led_strip.h"
#include "driver/gpio.h"
  #include "soc/soc.h"
    #include "soc/rtc_cntl_reg.h"
// #include "driver/i2c.h"
// #include "kode_bq25896.h"
// #include "esp_ble_conn_mgr.h"
// #include "nvs_flash.h"

static const char *TAG = "WS2812B_LED";

// LED strip configuration
#define LED_STRIP_LED_NUMBERS 20
#define LED_STRIP_RMT_RES_HZ  (10 * 1000 * 1000) // 10MHz resolution, 1 tick = 0.1us
#define LED_GPIO_PIN          18  // GPIO 18 as shown in pinout diagram

// I2C configuration for BQ25896 PMIC (commented out)
// #define I2C_MASTER_SCL_IO     21  // GPIO 21 (Pin 33) - I2C_SCL
// #define I2C_MASTER_SDA_IO     22  // GPIO 22 (Pin 36) - I2C_SDA
// #define I2C_MASTER_NUM        I2C_NUM_0

// BLE configuration (commented out)
// #define BLE_DEVICE_NAME       "Luma"
// #define BLE_BROADCAST_DATA    "LED Monitor"

// LED color configuration - toggle between warm orange and minecraft blue
#define USE_WARM_ORANGE       1  // Set to 1 for warm orange, 0 for minecraft blue

#if USE_WARM_ORANGE
    #define LED_RED           255
    #define LED_GREEN         100
    #define LED_BLUE          0
    #define COLOR_NAME        "Warm Orange"
#else
    #define LED_RED           5
    #define LED_GREEN         0
    #define LED_BLUE          159
    #define COLOR_NAME        "Minecraft Blue"
#endif

// LED strip handle
static led_strip_handle_t led_strip;

// BQ25896 PMIC handles (commented out)
// static i2c_master_bus_handle_t i2c_bus = NULL;
// static bq25896_handle_t bq_handle = NULL;
// static bool bq25896_initialized = false;

// Function to initialize LED strip
static void led_strip_init(void)
{
    ESP_LOGI(TAG, "Initializing LED strip...");
    
    // LED strip general configuration
    led_strip_config_t strip_config = {
        .strip_gpio_num = LED_GPIO_PIN,   // The GPIO that connected to the LED strip's data line
        .max_leds = LED_STRIP_LED_NUMBERS, // The number of LEDs in the strip
        .led_model = LED_MODEL_WS2812,    // LED strip model, it determines the bit timing
        .color_component_format = LED_STRIP_COLOR_COMPONENT_FMT_GRB, // The color component format is G-R-B
        .flags = {
            .invert_out = false, // don't invert the output signal
        }
    };

    // LED strip RMT configuration
    led_strip_rmt_config_t rmt_config = {
        .clk_src = RMT_CLK_SRC_DEFAULT,        // different clock source can lead to different power consumption
        .resolution_hz = LED_STRIP_RMT_RES_HZ, // RMT counter clock frequency: 10MHz
        .mem_block_symbols = 64,               // the memory size of each RMT channel, in words (4 bytes)
        .flags = {
            .with_dma = false, // DMA feature is available on chips like ESP32-S3/P4
        }
    };

    // LED Strip object handle
    ESP_ERROR_CHECK(led_strip_new_rmt_device(&strip_config, &rmt_config, &led_strip));
    ESP_LOGI(TAG, "Created LED strip object with RMT backend");
}

// Function to initialize BQ25896 PMIC
// static esp_err_t bq25896_pmic_init(void)
// {
//     ESP_LOGI(TAG, "Starting BQ25896 PMIC initialization");
    
//     // Initialize I2C bus
//     i2c_master_bus_config_t i2c_bus_config = {
//         .clk_source = I2C_CLK_SRC_DEFAULT,
//         .i2c_port = I2C_MASTER_NUM,
//         .scl_io_num = I2C_MASTER_SCL_IO,
//         .sda_io_num = I2C_MASTER_SDA_IO,
//         .glitch_ignore_cnt = 7,
//         .flags.enable_internal_pullup = true,
//     };

//     esp_err_t ret = i2c_new_master_bus(&i2c_bus_config, &i2c_bus);
//     if (ret != ESP_OK) {
//         ESP_LOGE(TAG, "Failed to initialize I2C bus: %s", esp_err_to_name(ret));
//         return ret;
//     }
//     ESP_LOGI(TAG, "I2C bus initialized successfully");
    
//     // Initialize BQ25896 PMIC with default configuration
//     ret = bq25896_init(i2c_bus, &bq_handle);
//     if (ret != ESP_OK) {
//         ESP_LOGE(TAG, "Failed to initialize BQ25896: %s", esp_err_to_name(ret));
//         i2c_del_master_bus(i2c_bus);
//         return ret;
//     }
//     ESP_LOGI(TAG, "BQ25896 initialized successfully with default configuration");
    
//     bq25896_initialized = true;
//     return ESP_OK;
// }

// // Function to initialize BLE connection manager
// static esp_err_t ble_conn_mgr_init(void)
// {
//     ESP_LOGI(TAG, "Initializing BLE connection manager...");
    
//     // Add delay to allow power to stabilize after brownout
//     vTaskDelay(pdMS_TO_TICKS(1000));
//     ESP_LOGI(TAG, "Power stabilization delay completed");
    
//     // Configure BLE connection manager
//     esp_ble_conn_config_t config = {
//         .device_name = BLE_DEVICE_NAME,
//         .broadcast_data = BLE_BROADCAST_DATA
//     };
    
//     // Initialize BLE connection manager
//     esp_err_t ret = esp_ble_conn_init(&config);
//     if (ret != ESP_OK) {
//         ESP_LOGE(TAG, "Failed to initialize BLE connection manager: %s", esp_err_to_name(ret));
//         ESP_LOGE(TAG, "This may be due to power supply issues or RF calibration problems");
//         return ret;
//     }
    
//     // Add delay before starting BLE
//     vTaskDelay(pdMS_TO_TICKS(500));
    
//     // Start BLE connection manager
//     ret = esp_ble_conn_start();
//     if (ret != ESP_OK) {
//         ESP_LOGE(TAG, "Failed to start BLE connection manager: %s", esp_err_to_name(ret));
//         return ret;
//     }
    
//     ESP_LOGI(TAG, "BLE connection manager initialized successfully");
//     ESP_LOGI(TAG, "Device name: %s", BLE_DEVICE_NAME);
//     ESP_LOGI(TAG, "Broadcast data: %s", BLE_BROADCAST_DATA);
    
//     return ESP_OK;
// }

// Function to log battery status
// static void log_battery_status(void)
// {
//     if (!bq25896_initialized) {
//         ESP_LOGW(TAG, "BQ25896 not initialized, cannot read battery status");
//         return;
//     }
    
//     // Read battery voltage
//     uint16_t battery_voltage_mv;
//     esp_err_t ret = bq25896_get_battery_voltage(bq_handle, &battery_voltage_mv);
//     if (ret == ESP_OK) {
//         ESP_LOGI(TAG, "Battery Voltage: %.3fV", battery_voltage_mv / 1000.0f);
//     } else {
//         ESP_LOGE(TAG, "Failed to read battery voltage: %s", esp_err_to_name(ret));
//     }
    
//     // Read system voltage
//     uint16_t system_voltage_mv;
//     ret = bq25896_get_system_voltage(bq_handle, &system_voltage_mv);
//     if (ret == ESP_OK) {
//         ESP_LOGI(TAG, "System Voltage: %.3fV", system_voltage_mv / 1000.0f);
//     } else {
//         ESP_LOGE(TAG, "Failed to read system voltage: %s", esp_err_to_name(ret));
//     }
    
//     // Read VBUS voltage
//     uint16_t vbus_voltage_mv;
//     ret = bq25896_get_vbus_voltage(bq_handle, &vbus_voltage_mv);
//     if (ret == ESP_OK) {
//         ESP_LOGI(TAG, "VBUS Voltage: %.3fV", vbus_voltage_mv / 1000.0f);
//     } else {
//         ESP_LOGE(TAG, "Failed to read VBUS voltage: %s", esp_err_to_name(ret));
//     }
    
//     // Read charge current
//     uint16_t charge_current_ma;
//     ret = bq25896_get_charge_current(bq_handle, &charge_current_ma);
//     if (ret == ESP_OK) {
//         ESP_LOGI(TAG, "Charge Current: %.3fA", charge_current_ma / 1000.0f);
//     } else {
//         ESP_LOGE(TAG, "Failed to read charge current: %s", esp_err_to_name(ret));
//     }
    
//     // Read charge status
//     bq25896_chrg_stat_t charge_status;
//     ret = bq25896_get_charging_status(bq_handle, &charge_status);
//     if (ret == ESP_OK) {
//         const char* status_strings[] = {
//             "Not Charging", "Pre-charge", "Fast Charging", "Charge Done"
//         };
//         ESP_LOGI(TAG, "Charge Status: %s", status_strings[charge_status]);
//     } else {
//         ESP_LOGE(TAG, "Failed to read charge status: %s", esp_err_to_name(ret));
//     }
    
//     // Read VBUS status
//     bq25896_vbus_stat_t vbus_status;
//     ret = bq25896_get_vbus_status(bq_handle, &vbus_status);
//     if (ret == ESP_OK) {
//         const char* vbus_strings[] = {
//             "No Input", "USB Host SDP", "Adapter (3.25A)", "Unknown", 
//             "Unknown", "Unknown", "Unknown", "OTG"
//         };
//         ESP_LOGI(TAG, "VBUS Status: %s", vbus_strings[vbus_status]);
//     } else {
//         ESP_LOGE(TAG, "Failed to read VBUS status: %s", esp_err_to_name(ret));
//     }
    
//     // Read power good status
//     bq25896_pg_stat_t power_good;
//     ret = bq25896_get_pg_status(bq_handle, &power_good);
//     if (ret == ESP_OK) {
//         ESP_LOGI(TAG, "Power Good: %s", power_good ? "Yes" : "No");
//     } else {
//         ESP_LOGE(TAG, "Failed to read power good status: %s", esp_err_to_name(ret));
//     }
    
//     // Read VSYS regulation status
//     bq25896_vsys_stat_t vsys_status;
//     ret = bq25896_get_vsys_status(bq_handle, &vsys_status);
//     if (ret == ESP_OK) {
//         ESP_LOGI(TAG, "VSYS Regulation: %s", vsys_status ? "Active" : "Inactive");
//     } else {
//         ESP_LOGE(TAG, "Failed to read VSYS status: %s", esp_err_to_name(ret));
//     }
    
//     // Read fault status
//     bq25896_watchdog_fault_t wd_fault;
//     bq25896_boost_fault_t boost_fault;
//     bq25896_chrg_fault_t chrg_fault;
//     bq25896_bat_fault_t bat_fault;
//     bq25896_ntc_fault_t ntc_fault;
    
//     ret = bq25896_get_watchdog_fault(bq_handle, &wd_fault);
//     if (ret == ESP_OK && wd_fault) {
//         ESP_LOGW(TAG, "Watchdog fault detected");
//     }
    
//     ret = bq25896_get_boost_fault(bq_handle, &boost_fault);
//     if (ret == ESP_OK && boost_fault) {
//         ESP_LOGW(TAG, "Boost fault detected");
//     }
    
//     ret = bq25896_get_charge_fault(bq_handle, &chrg_fault);
//     if (ret == ESP_OK && chrg_fault != BQ25896_CHRG_FAULT_NORMAL) {
//         const char* fault_strings[] = {
//             "Normal", "Input Fault", "Thermal Shutdown", "Timer Expired"
//         };
//         ESP_LOGW(TAG, "Charge fault: %s", fault_strings[chrg_fault]);
//     }
    
//     ret = bq25896_get_battery_fault(bq_handle, &bat_fault);
//     if (ret == ESP_OK && bat_fault) {
//         ESP_LOGW(TAG, "Battery overvoltage fault detected");
//     }
    
//     ret = bq25896_get_ntc_fault(bq_handle, &ntc_fault);
//     if (ret == ESP_OK && ntc_fault != BQ25896_NTC_FAULT_NORMAL) {
//         const char* ntc_strings[] = {
//             "Normal", "Unknown", "TS Warm", "TS Cool", "Unknown", "TS Cold", "TS Hot"
//         };
//         ESP_LOGW(TAG, "NTC fault: %s", ntc_strings[ntc_fault]);
//     }
// }

// Function to set all LEDs to a specific color
static void set_all_leds_color(uint32_t red, uint32_t green, uint32_t blue)
{
    for (int i = 0; i < LED_STRIP_LED_NUMBERS; i++) {
        ESP_ERROR_CHECK(led_strip_set_pixel(led_strip, i, red, green, blue));
    }
    ESP_ERROR_CHECK(led_strip_refresh(led_strip));
}

// Function to clear all LEDs
static void clear_all_leds(void)
{
    set_all_leds_color(0, 0, 0);
}

// Rainbow and chasing effects removed - using single color mode only

// Battery monitoring task
// static void battery_monitor_task(void *pvParameters)
// {
//     ESP_LOGI(TAG, "Starting battery monitoring task");
    
//     while (1) {
//         // Log battery status every 10 seconds
//         log_battery_status();
//         ESP_LOGI(TAG, "--- Battery Status Log Complete ---");
//         vTaskDelay(pdMS_TO_TICKS(10000)); // 10 second delay
//     }
// }

// LED control task
static void led_task(void *pvParameters)
{
    ESP_LOGI(TAG, "Starting LED control task");
    ESP_LOGI(TAG, "Using color: %s (R:%d, G:%d, B:%d)", COLOR_NAME, LED_RED, LED_GREEN, LED_BLUE);
    
    // Clear all LEDs first to remove any residual state
    ESP_LOGI(TAG, "Clearing all LEDs before starting");
    clear_all_leds();
    vTaskDelay(pdMS_TO_TICKS(500)); // Brief delay to ensure clear is visible
    
    // Set LEDs once to the selected color (reduced brightness)
    ESP_LOGI(TAG, "Setting all LEDs to %s", COLOR_NAME);
    // Reduce brightness to lower power consumption and get proper orange
    set_all_leds_color(LED_RED/2, LED_GREEN/2, LED_BLUE/2);
    ESP_LOGI(TAG, "LEDs set to constant color, entering idle state");
    
    while (1) {
        // Just keep the task alive - LEDs remain on
        vTaskDelay(pdMS_TO_TICKS(5000)); // 5 second idle delay
    }
}

void app_main(void)
{
    printf("ESP32 WS2812B LED Controller - Single Color Mode\n");
    printf("Controlling %d WS2812B LEDs on GPIO %d\n", LED_STRIP_LED_NUMBERS, LED_GPIO_PIN);
    printf("LED Color: %s (R:%d, G:%d, B:%d)\n", COLOR_NAME, LED_RED, LED_GREEN, LED_BLUE);
    
    // Disable brownout detector to prevent resets (TEMPORARY FIX)
    // WARNING: This masks power supply issues - fix hardware instead!
    WRITE_PERI_REG(RTC_CNTL_BROWN_OUT_REG, 0);
        ESP_LOGW(TAG, "Brownout detector disabled - fix power supply issues!");

    // NVS initialization (commented out - not needed for LED only)
    // esp_err_t ret = nvs_flash_init();
    // ... NVS code commented out ...

    /* Print chip information */
    esp_chip_info_t chip_info;
    uint32_t flash_size;
    esp_chip_info(&chip_info);
    printf("This is %s chip with %d CPU core(s), %s%s%s%s, ",
           CONFIG_IDF_TARGET,
           chip_info.cores,
           (chip_info.features & CHIP_FEATURE_WIFI_BGN) ? "WiFi/" : "",
           (chip_info.features & CHIP_FEATURE_BT) ? "BT" : "",
           (chip_info.features & CHIP_FEATURE_BLE) ? "BLE" : "",
           (chip_info.features & CHIP_FEATURE_IEEE802154) ? ", 802.15.4 (Zigbee/Thread)" : "");

    unsigned major_rev = chip_info.revision / 100;
    unsigned minor_rev = chip_info.revision % 100;
    printf("silicon revision v%d.%d, ", major_rev, minor_rev);
    if(esp_flash_get_size(NULL, &flash_size) != ESP_OK) {
        printf("Get flash size failed");
        return;
    }

    printf("%" PRIu32 "MB %s flash\n", flash_size / (uint32_t)(1024 * 1024),
           (chip_info.features & CHIP_FEATURE_EMB_FLASH) ? "embedded" : "external");

    printf("Minimum free heap size: %" PRIu32 " bytes\n", esp_get_minimum_free_heap_size());

    // Add delay to allow power to stabilize
    ESP_LOGI(TAG, "Allowing power to stabilize...");
    vTaskDelay(pdMS_TO_TICKS(2000));
    
    // Initialize LED strip
    led_strip_init();
    
    // BLE and BQ25896 initialization (commented out)
    // ret = ble_conn_mgr_init();
    // ret = bq25896_pmic_init();
    // ... BLE and battery monitoring code commented out ...
    
    // Create LED control task with lower priority to reduce power spikes
    xTaskCreate(led_task, "led_task", 4096, NULL, 3, NULL);
    
    printf("LED control task started. LEDs will begin cycling through patterns.\n");
}

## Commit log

2025-07-18 adds schmatic ansd sart of boeard
    [luma.kicad_pcb, luma.kicad_sch]
2025-07-18 added stuff
    [luma.kicad_pcb, luma.kicad_sch]
2025-07-26 added bottom insets
    [Bottom.step, Luma v26.f3z, Luma v29.f3z]
2025-07-30 fix pcb placement
    [luma.kicad_pcb, positions.csv]
2025-07-30 adddd winsow and insets
    [Top.step, Window.step]
2025-07-30 udpated with window
    [Luma v29.f3z, Luma v33.f3z]
2025-08-14 added tolerances an finished build
    [Base_Complete.step, Luma v40.f3z, Top_Complete.step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]
